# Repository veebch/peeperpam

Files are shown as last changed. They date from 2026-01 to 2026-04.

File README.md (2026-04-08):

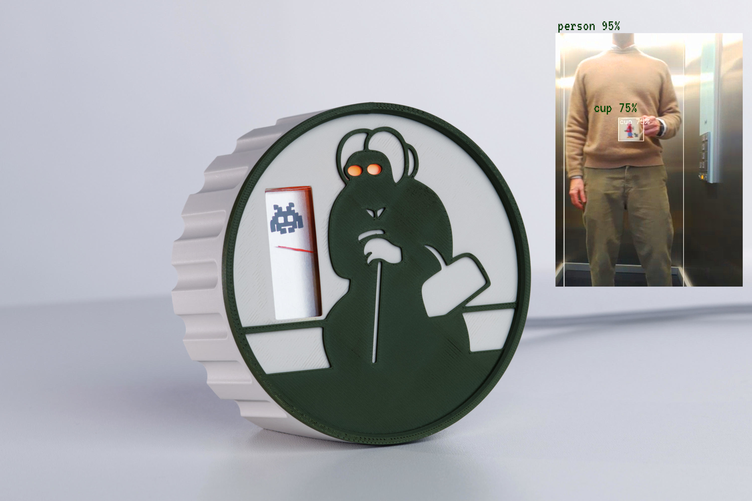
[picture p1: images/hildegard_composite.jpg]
Sketch


 

# Hildegard

A Computer Vision Sentry 

It uses a Raspberry Pi 5 with a camera and Raspberry Pi AI HAT+ 2 as the server, and a Pico W as the client. The system detects all objects but provides priority-based responses: person+cup combinations trigger 100% alerts, person detection alone triggers 70% response, cup detection triggers 30% response, and other interesting objects trigger 10% response. Alerts are sent via WebSocket with RGB LED color changes, PWM-controlled analog needle movement showing detection confidence, and UFO sound alerts for detections above 50% threshold.

## Explainer Video

Here's an overview video of the build and a demo of it in action (it shows the initial red led only version):

YouTube (https://www.youtube.com/watch?v=Vn3WaVIr5v0)

## Project Structure

### Server Components
- **combined_monitor.py** - Complete Raspberry Pi camera monitoring system that captures video, performs object detection using AI kit, and broadcasts all detected objects with confidence scores via WebSocket

### Client Components  
- **main.py** - MicroPython WebSocket client for Pico W that receives detection data and provides priority-based responses:
  - Person + Cup: 100% PWM alert
  - Person only: 70% PWM response 
  - Cup only: 30% PWM response
  - Other objects: 10% PWM response
  - LED color transitions from green (0%) to red (100%) based on detection priority

##  Materials
### Server 
- Raspberry Pi 5
- Raspberry Pi AI+ 2 Kit
- Camera module 

### Detector
- Analogue voltmeter (5V) 
- Pico W
- 220 Ohm resistor
- 1K Ohm resistor
- MOSFET (We used a Small Signal BS170)
- A 4 legged RGB LED
- Passive buzzer

## Assembly

### Server

Connect the M2 expansion board from the AI kit to the Pi 5, connect the 22 pin ribbon cable from the CAM/DISP 0 port on the Pi.

### Detector

- From the Pico, GPIO 27 is soldered to the 1K Ohm resistor which in turn is soldered to the gate (middle pin) of the MOSFET. 
- The VSYS connection on the Pico is connected the positive terminal of the voltmeter. 
- The Cathode (negative) leg of the LED is connected to a GND pin on the Pico in series with the 220 ohm resistor. The Red, Green and Blue legs are connected to GP18, GP19 and GP20 respectively
- The passive buzzer positive terminal is connected to GPIO 15, and the negative terminal to GND
- The Source leg of the MOSFET is connected to the Negative terminal on the voltmeter, the Drain leg of the MOSFET is then connected to a GND GPIO on the Pico W. 

## Installing

First, make sure you have the rpicam-apps files in your home directory
```
cd ~
git clone https://github.com/raspberrypi/rpicam-apps
```

Copy this repository to the Pi 5 using the commands 
```
git clone https://github.com/veebch/peeperpam.git
```
Then copy the file `main.py` to the pico using Ampy (or Thonny)

## Running

### Prerequisites
Make sure you have the rpicam-apps installed:
```bash
cd ~
git clone https://github.com/raspberrypi/rpicam-apps
```

### Start the Complete Monitoring System
Set up Python environment and run the integrated server:
```bash
python3 -m venv ~/.venv
source ~/.venv/bin/activate
cd ~/peeperpam
pip install websockets  # Install required WebSocket library
python3 combined_monitor.py
```

This single command starts both the camera monitoring and WebSocket server that broadcasts all detected objects.

### Configure and Deploy the Client
1. **Edit configuration in `config.py`**:
   - WiFi credentials: Replace `SSID` and `PASSWORD` with your network details
   - Object detection: Customize `INTERESTING_OBJECTS` list to monitor different objects (from the [COCO 80](https://blog.roboflow.com/microsoft-coco-classes/) list by default but you can train on other image data)
   - Detection priorities: Adjust `PERSON_SCALE`, `CUP_SCALE`, and `OTHER_SCALE` values
   - Sound settings: Modify `SOUND_THRESHOLD`, `SOUND_COOLDOWN`, and UFO sound parameters
   - Hardware pins: Change pin assignments if using different GPIO connections

2. Copy both `main.py` and `config.py` to your Pico W using Ampy, Thonny, or your preferred method

3. Power on the Pico W - it will automatically connect to WiFi and start receiving detection alerts

### System Operation
- The system detects all objects but responds with different priority levels
- RGB LED changes from green (low priority) to red (high priority) 
- Analog needle shows detection confidence scaled by priority level
- UFO sound alert plays when detection confidence exceeds 50% threshold
- Sound includes 5-second cooldown to prevent constant triggering
- WebSocket connection automatically reconnects if interrupted

## Caveats

The MOSFET may be overkill for the LED and Voltmeter, but if you plan to use something that draws more current than an LED, then using SYSBUS means the 'alarm' peripheral can draw a lot more current than just a GPIO pin set to high (~16mA).

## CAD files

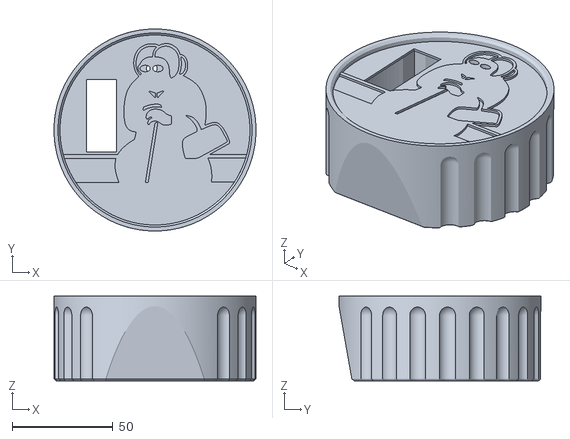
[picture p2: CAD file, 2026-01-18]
3d/Hildegard-enclosure.stl
100.0 x 100.0 x 42.0

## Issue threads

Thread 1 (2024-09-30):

Pico W Detector Details

holmesha, 2024-09-30:
Hello! I was wondering if you could provide a bit more detail on the detector connections. Maybe a diagram or a picture where I can see the wires? I'm not great at the electrical engineering part, but I love the idea of the detector. I'm going to attempt to train the model to recognize raccoons because I have a family of racoons making my cat's life a nightmare lol, but I never catch them in the act!

veebch, 2024-09-30:
Hey there,  Racooncam sounds like a winner. I'll add a photo to the readme this  morning. Hopefully the janky soldering will not cause too many screams on the internet. I'll leave this open until I actually add the photo.

veebch, 2024-09-30:
Done! I want a racoon update once it's all done :)

Closed 2024-09-30.

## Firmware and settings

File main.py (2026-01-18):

import network
import usocket as socket
import ubinascii
import uasyncio as asyncio
import os
import time
import re
import ujson as json
import math
from machine import Pin, PWM
from config import *

# Hardware pin definitions
RED_PIN = 18
GREEN_PIN = 19
BLUE_PIN = 20
ALERT_PIN = 27
BUZZER_PIN = 15

# Startup sequence timing
STARTUP_RAMP_DURATION = 2.0  # Seconds for ramp up/down
STARTUP_STEPS = 100          # Number of steps in ramp sequence

# RGB LED pins with PWM
red_pin = PWM(Pin(RED_PIN))
green_pin = PWM(Pin(GREEN_PIN))
blue_pin = PWM(Pin(BLUE_PIN))

# Set PWM frequency for LED
for pin in [red_pin, green_pin, blue_pin]:
    pin.freq(1000)
    pin.duty_u16(0)

# Alert PWM pin
alert = PWM(Pin(ALERT_PIN))
alert.freq(1000)

# Buzzer pin for sound alerts
buzzer = PWM(Pin(BUZZER_PIN))
buzzer.duty_u16(0)  # start silent

# Sound threshold and state tracking
sound_playing = False
last_sound_time = 0

# Connect to Wi-Fi
print("Connecting to WiFi network:", SSID)
wlan = network.WLAN(network.STA_IF)
wlan.active(True)
print("WiFi interface activated")

# Force fresh connection - disconnect first if connected
if wlan.isconnected():
    print("Forcing WiFi disconnect to ensure fresh connection...")
    wlan.disconnect()
    time.sleep(2)  # Wait for disconnect
    print("WiFi disconnected")

print("Attempting to connect...")
wlan.connect(SSID, PASSWORD)
print("Connection request sent, waiting for connection...")

connection_attempts = 0
while not wlan.isconnected() and connection_attempts < WIFI_MAX_ATTEMPTS:
    connection_attempts += 1
    if connection_attempts % 10 == 0:  # Log every 1 second
        print("Still connecting... (attempt", connection_attempts, ")")
    time.sleep(WIFI_RETRY_DELAY)

if not wlan.isconnected():
    print("Failed to connect to WiFi after", WIFI_MAX_ATTEMPTS/10, "seconds")
    print("WiFi Status:", wlan.status())
    print("Check your SSID and password")
    # Don't continue without WiFi
    while True:
        time.sleep(1)

print("Connected to Wi-Fi successfully")
ip_info = wlan.ifconfig()
print("IP Address:", ip_info[0])
print("Subnet Mask:", ip_info[1])
print("Gateway:", ip_info[2])
print("DNS:", ip_info[3])

# Wait a moment for network stack to fully initialize
print("Waiting for network stack to stabilize...")
time.sleep(NETWORK_STABILIZE_DELAY)

def set_rgb_pwm(r, g, b):
    """Set RGB LED color using PWM values (0-65535)"""
    red_pin.duty_u16(r)
    green_pin.duty_u16(g)
    blue_pin.duty_u16(b)

def update_led_from_pwm(duty_ratio):
    """Update LED color based on PWM duty cycle (0.0 to 1.0)
    Green at 0%, transitions to red at 100%"""
    red = int(duty_ratio * 65535)
    green = int((1 - duty_ratio) * 65535)
    set_rgb_pwm(red, green, 0)

def set_duty_cycle(duty, verbose=True):
    # Clamp duty to 0.0-1.0 range
    original_duty = duty
    duty = max(0.0, min(1.0, duty))
    if original_duty != duty and verbose:
        print("WARNING: Duty cycle clamped from", original_duty, "to", duty)
    
    pwm_value = int(duty * 65535)
    alert.duty_u16(pwm_value)
    if verbose:
        print("PWM set to", duty, "(", pwm_value, "/65535)")
    
    # Update LED color to match PWM value
    update_led_from_pwm(duty)
    if verbose:
        red_val = int(duty*65535)
        green_val = int((1-duty)*65535)
        print("LED color updated (red:", red_val, ", green:", green_val, ")")

async def play_ufo_sound():
    """Play UFO sound effect asynchronously"""
    global sound_playing
    sound_playing = True
    print("Playing UFO sound alert!")
    
    start_time = time.ticks_us()
    total_time = UFO_FADE_IN_SEC + UFO_SUSTAIN_SEC + UFO_FADE_OUT_SEC
    
    try:
        while True:
            # Elapsed time in seconds
            t = time.ticks_diff(time.ticks_us(), start_time) / 1_000_000
            if t > total_time:
                break  # stop after full sound duration

            # Fade-in / sustain / fade-out scaling
            if t < UFO_FADE_IN_SEC:
                scale = t / UFO_FADE_IN_SEC
            elif t < UFO_FADE_IN_SEC + UFO_SUSTAIN_SEC:
                scale = 1.0
            else:
                scale = (total_time - t) / UFO_FADE_OUT_SEC

            # Pitch modulation (LFO)
            pitch_mod = math.sin(2 * math.pi * UFO_LFO_RATE * t)
            freq = int(UFO_BASE_FREQ + UFO_FREQ_DEPTH * pitch_mod)
            buzzer.freq(freq)

            # Volume modulation with global volume
            phase_vol = 2 * math.pi * UFO_LFO_RATE * t + math.pi / 4
            vol_mod = (math.sin(phase_vol) * UFO_VOLUME_DEPTH + 1 - UFO_VOLUME_DEPTH) / 2
            vol_mod *= UFO_VOLUME

            # Duty cycle with fade
            buzzer.duty_u16(int(vol_mod * scale * 65535))

            await asyncio.sleep_ms(UFO_STEP_MS)

    except Exception as e:
        print("Sound error:", e)
    finally:
        buzzer.duty_u16(0)  # ensure buzzer is silent
        sound_playing = False
        print("UFO sound complete")

async def startup_sequence():
    """Startup sequence: ramp up to full over 2 seconds, then down over 2 seconds"""
    global last_sound_time, sound_playing
    
    step_duration = STARTUP_RAMP_DURATION / STARTUP_STEPS
    sound_triggered = False  # Track if we've triggered sound during startup

    # Ramp up (reduce logging)
    print("Starting up - ramping up...")
    for i in range(STARTUP_STEPS + 1):
        duty = i / STARTUP_STEPS
        set_duty_cycle(duty, verbose=False)  # Suppress verbose output during startup
        
        # Check if we should trigger sound during startup ramp
        if (duty > SOUND_THRESHOLD and 
            not sound_triggered and 
            not sound_playing):
            
            print(f"Startup PWM reached threshold ({duty:.2f} > {SOUND_THRESHOLD}) - triggering startup sound!")
            sound_triggered = True
            last_sound_time = time.time()  # Update last sound time
            # Start sound in background
            asyncio.create_task(play_ufo_sound())
        
        await asyncio.sleep(step_duration)

    # Ramp down
    print("Ramping down...")
    for i in range(STARTUP_STEPS, -1, -1):
        duty = i / STARTUP_STEPS
        set_duty_cycle(duty, verbose=False)  # Suppress verbose output during startup
        await asyncio.sleep(step_duration)

    print("Startup complete")

class WebSocketClient:
    def __init__(self, server_ip, port):
        self.server_ip = server_ip
        self.port = port
        self.sock = None

    def connect(self):
        while True:
            try:
                print("Resolving server address...")
                addr_info = socket.getaddrinfo(self.server_ip, self.port, socket.AF_INET)  # Force IPv4
                addr = addr_info[0][-1]
                print("Server address resolved to:", addr)
                
                print("Creating socket...")
                self.sock = socket.socket()
                print("Connecting to server...")
                self.sock.connect(addr)
                print("Connected to", self.server_ip, ":", self.port)

                # Handshake - use original working format
                sec_websocket_key = ubinascii.b2a_base64(os.urandom(16)).strip()
                handshake = (b"GET / HTTP/1.1\r\n"
                             b"Host: %s:%d\r\n"
                             b"Upgrade: websocket\r\n"
                             b"Connection: Upgrade\r\n"
                             b"Sec-WebSocket-Key: %s\r\n"
                             b"Sec-WebSocket-Version: 13\r\n\r\n") % (self.server_ip.encode(), self.port, sec_websocket_key)
                self.sock.send(handshake)
                response = self.sock.recv(1024)
                print("Handshake response:", response)
                if b"101" not in response:
                    raise ValueError("Handshake failed")
                print("Handshake successful")
                break
            except (OSError, ValueError) as e:
                print("Connection error:", e)
                print("Error type:", type(e).__name__)
                if hasattr(e, 'errno'):
                    print("Error number:", e.errno)
                if self.sock:
                    self.sock.close()
                self.sock = None
                print("Retrying connection in 5 seconds...")
                time.sleep(WEBSOCKET_RETRY_DELAY)

    def read_bytes(self, num_bytes):
        data = bytearray()
        while len(data) < num_bytes:
            packet = self.sock.recv(num_bytes - len(data))
            if not packet:
                raise ValueError("Connection closed before receiving all data")
            data.extend(packet)
        return data

    def recv(self):
        try:
            first_byte, second_byte = self.read_bytes(2)
            fin = first_byte & 0b10000000
            opcode = first_byte & 0b00001111
            masked = second_byte & 0b10000000
            payload_length = second_byte & 0b01111111

            if payload_length == 126:
                payload_length = int.from_bytes(self.read_bytes(2), 'big')
            elif payload_length == 127:
                payload_length = int.from_bytes(self.read_bytes(8), 'big')

            if masked:
                masking_key = self.read_bytes(4)
                payload = bytearray(self.read_bytes(payload_length))
                for i in range(payload_length):
                    payload[i] ^= masking_key[i % 4]
            else:
                payload = self.read_bytes(payload_length)

            if opcode == 0x8:  # Close frame
                print("Received close frame")
                self.send_close_frame()
                return None

            if opcode == 0x9:  # Ping frame
                print("Received ping frame")
                self.send_pong_frame()
                return None

            message = payload.decode('utf-8')
            print("Received message:", message)
            return message
        except OSError as e:
            print("Recv error:", e)
            self.close()
            return None

    def send_frame(self, opcode, payload=b''):
        frame = bytearray()
        frame.append(0x80 | opcode)
        payload_length = len(payload)
        if payload_length < 126:
            frame.append(0x80 | payload_length)
        elif payload_length <= 0xFFFF:
            frame.append(0x80 | 126)
            frame.extend(payload_length.to_bytes(2, 'big'))
        else:
            frame.append(0x80 | 127)
            frame.extend(payload_length.to_bytes(8, 'big'))
        masking_key = os.urandom(4)
        frame.extend(masking_key)
        if payload:
            masked_payload = bytearray(payload)
            for i in range(len(masked_payload)):
                masked_payload[i] ^= masking_key[i % 4]
            frame.extend(masked_payload)
        self.sock.send(frame)

    def send_close_frame(self):
        self.send_frame(0x8)
        print("Close frame sent")

    def send_pong_frame(self):
        self.send_frame(0xA)
        print("Pong frame sent")

    def close(self):
        if self.sock:
            try:
                self.send_close_frame()
            except Exception as e:
                print("Error during close frame:", e)
            self.sock.close()
            self.sock = None
        print("Socket closed")

def parse_detection_data(message):
    """Parse detection data and return appropriate PWM duty cycle"""
    print("Parsing detection data...")
    try:
        data = json.loads(message)
        print("Successfully parsed JSON data")
        
        all_objects = data.get("all_objects", {})
        avg_confidence = data.get("average_confidence", 0.0)
        is_alert = data.get("alert", False)
        
        if all_objects:
            print("All objects detected:", all_objects)
            
            # Priority 1: High alert for person+cup combination
            if is_alert:
                print("HIGH PRIORITY ALERT!")
                conf_percent = avg_confidence * 100
                print("Alert confidence:", avg_confidence, "(", conf_percent, "%)")
                return avg_confidence
            
            # Priority 2: Respond to person detection (medium priority)
            elif "person" in all_objects:
                person_data = all_objects["person"]
                if isinstance(person_data, dict):
                    person_conf = person_data["confidence"]
                    print("Person detected - confidence:", person_conf)
                    # Scale down for person-only detection
                    return person_conf * PERSON_SCALE
                    
            # Priority 3: Respond to cup detection (lower priority)
            elif "cup" in all_objects:
                cup_data = all_objects["cup"]
                if isinstance(cup_data, dict):
                    cup_conf = cup_data["confidence"]
                    print("Cup detected - confidence:", cup_conf)
                    # Scale down for cup-only detection
                    return cup_conf * CUP_SCALE
                    
            # Priority 4: Other interesting objects (very low response)
            else:
                for obj in INTERESTING_OBJECTS:
                    if obj in all_objects:
                        obj_data = all_objects[obj]
                        if isinstance(obj_data, dict):
                            obj_conf = obj_data["confidence"]
                            print(obj + " detected - confidence:", obj_conf)
                            # Very low response for other objects
                            return obj_conf * OTHER_SCALE
                            
                print("Objects detected but no priority matches")
                
        return 0.0  # No significant objects detected
            
    except (ValueError, KeyError) as e:
        
        # Fallback to old string parsing for compatibility
        return parse_string_legacy(message)
    
    return 0.0

def parse_string_legacy(input_string):
    """Legacy string parsing for backward compatibility"""
    # Check if the string contains the word 'person'
    if 'person' in input_string:
        # Use regex to find the number in parentheses
        match = re.search(r'\(([\d.]+)\)', input_string)
        if match:
            number_in_parentheses = float(match.group(1))
        else:
            number_in_parentheses = 0
    else:
        number_in_parentheses = 0

    return number_in_parentheses

async def perform_action(signal):
    global last_sound_time, sound_playing
    print("Processing detection signal!")
    # Parse the detection data (JSON or legacy string)
    duty = parse_detection_data(signal)
    if duty > 0:
        print("Setting PWM duty to:", duty)
        set_duty_cycle(duty)
        
        # Check if we should trigger sound alert
        current_time = time.time()
        if (duty > SOUND_THRESHOLD and 
            not sound_playing and 
            (current_time - last_sound_time) > SOUND_COOLDOWN):
            
            print(f"Detection above threshold ({duty:.2f} > {SOUND_THRESHOLD}) - triggering sound!")
            last_sound_time = current_time
            # Start sound in background
            asyncio.create_task(play_ufo_sound())
        
    else:
        print("No significant detection - PWM remains at current level")

async def listen_for_signal():
    while True:
        ws = WebSocketClient(SERVER_IP, SERVER_PORT)
        try:
            ws.connect()
            while True:
                signal = ws.recv()
                if signal:
                    # Handle all JSON detection messages
                    if signal.startswith('{'):
                        print("Detection message received")
                        await perform_action(signal)
                    elif "Object" in signal or "person" in signal:
                        print("Legacy signal received:", signal)
                        await perform_action(signal)
                    else:
                        print("Server message:", signal)
        except Exception as e:
            print("Error:", e)
        finally:
            ws.close()
            await asyncio.sleep(WEBSOCKET_RETRY_DELAY)

async def main():
    """Main async function to run startup and then listen for signals"""
    # Run startup sequence
    await startup_sequence()
    # Start listening for detection signals
    await listen_for_signal()

# Run the main async function
asyncio.run(main())

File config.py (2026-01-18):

# PeeperPam Configuration File
# Edit these values to customize detection behavior and network settings

# ====== NETWORK SETTINGS ======
# WiFi credentials
SSID = "whyayefi"  # Replace with your actual WiFi SSID  
PASSWORD = "your_actual_password"  # Replace with your actual WiFi password

# Server connection
SERVER_IP = "peeper.local"  # Use hostname or IP address of your Raspberry Pi
SERVER_PORT = 6789

# ====== DETECTION PRIORITIES ======
# Object priority scaling factors (0.0 = no response, 1.0 = full response)
PERSON_SCALE = 0.7      # Person detection alone gets 70% response
CUP_SCALE = 0.3         # Cup detection alone gets 30% response  
OTHER_SCALE = 0.1       # Other interesting objects get 10% response

# High priority objects (will trigger person/cup scaled response)
PRIMARY_OBJECTS = ["person", "cup"]

# Interesting objects that trigger low-level responses
INTERESTING_OBJECTS = [
    "bottle", 
    "laptop", 
    "cell phone", 
    "book", 
    "tv",
    "mouse",
    "keyboard",
    "remote",
    "wine glass",
    "banana",
    "apple",
    "sandwich"
]

# ====== SOUND SETTINGS ======
# Sound trigger threshold (0.0 to 1.0)
SOUND_THRESHOLD = 0.5   # Trigger sound when detection confidence > 50%

# Sound timing
SOUND_COOLDOWN = 5.0    # Minimum seconds between sound triggers

# UFO sound parameters
UFO_BASE_FREQ = 600         # Base frequency (Hz)
UFO_FREQ_DEPTH = 300        # Pitch modulation depth
UFO_LFO_RATE = 15 / 2.3     # Pitch LFO frequency (Hz)
UFO_VOLUME_DEPTH = 0.3      # Amplitude modulation depth (0.0 - 1)
UFO_VOLUME = 1.0            # Global volume scale (0.0 - 1.0)

# Sound timing phases
UFO_FADE_IN_SEC = 0.1
UFO_SUSTAIN_SEC = 2.0
UFO_FADE_OUT_SEC = 1.0
UFO_STEP_MS = 5             # CPU delay between updates

# ====== CONNECTION SETTINGS ======
# WiFi connection parameters
WIFI_MAX_ATTEMPTS = 100     # Maximum connection attempts (10 seconds total)
WIFI_RETRY_DELAY = 0.1      # Seconds between connection attempts

# Network stabilization
NETWORK_STABILIZE_DELAY = 3  # Seconds to wait after WiFi connection

# WebSocket reconnection
WEBSOCKET_RETRY_DELAY = 5   # Seconds to wait before reconnecting on error

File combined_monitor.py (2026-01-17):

#!/usr/bin/env python3
import asyncio
import websockets
import subprocess
import re
import signal
import sys
import json
import time
import logging
import argparse
from collections import defaultdict
from datetime import datetime

class CameraMonitor:
    def __init__(self, show_preview=False):
        self.current_detection = {"person": 0, "cup": 0}
        self.current_confidence = {"person": 0.0, "cup": 0.0}
        self.all_objects = {}
        self.signal_active = False
        self.connected_clients = set()
        self.camera_process = None
        self.frame_count = 0
        self.last_detection_time = None
        self.show_preview = show_preview

        # Setup logging
        logging.basicConfig(
            level=logging.INFO,
            format='%(asctime)s - %(levelname)s - %(message)s',
            datefmt='%Y-%m-%d %H:%M:%S'
        )
        self.logger = logging.getLogger(__name__)

    async def start_camera_monitoring(self):
        """Start the camera process and monitor its output"""
        # Use different commands for preview vs headless mode
        if self.show_preview:
            # Use rpicam-hello for preview mode - it's designed for this
            cmd = [
                "rpicam-hello", "-v", "2", "-t", "0",
                "--post-process-file", "/home/pi/rpicam-apps/assets/hailo_yolov8_inference.json",
                "--lores-width", "640", "--lores-height", "640"
            ]
        else:
            # Use rpicam-vid for headless mode with output capture
            cmd = [
                "rpicam-vid", "-n", "-v", "2", "-t", "0", "--inline",
                "--post-process-file", "/home/pi/rpicam-apps/assets/hailo_yolov8_inference.json",
                "--width", "640", "--height", "640",
                "--framerate", "10", "-o", "-"
            ]

        mode = "with preview window (rpicam-hello)" if self.show_preview else "headless (rpicam-vid)"
        self.logger.info(f"Starting camera monitoring {mode}...")
        self.logger.info(f"Command: {' '.join(cmd)}")

        if self.show_preview:
            self.logger.info("📺 Preview window should appear for testing")
        else:
            self.logger.info("🔒 Running headless - suitable for SSH connections")

        try:
            self.camera_process = await asyncio.create_subprocess_exec(
                *cmd,
                stdout=subprocess.PIPE,
                stderr=subprocess.STDOUT
            )

            self.logger.info("Camera process started successfully")
            await self.process_camera_output()

        except Exception as e:
            self.logger.error(f"Error starting camera: {e}")

    async def process_camera_output(self):
        """Process camera output and detect objects"""
        if not self.camera_process:
            return

        self.logger.info("Starting camera output processing...")

        async for line_bytes in self.camera_process.stdout:
            try:
                line = line_bytes.decode('utf-8').strip()

                # Log all output for debugging (you can reduce this later)
                if line and not line.startswith('#'):
                    self.logger.debug(f"Camera output: {line}")

                # Parse YOLO detection output
                if self.is_detection_line(line):
                    self.frame_count += 1
                    self.last_detection_time = datetime.now()

                    self.logger.info(f"Frame {self.frame_count}: Processing detection line")
                    self.parse_detection_line(line)
                    await self.update_signal_status()

            except UnicodeDecodeError as e:
                self.logger.warning(f"Failed to decode line: {e}")
            except Exception as e:
                self.logger.error(f"Error processing camera output: {e}")

    def is_detection_line(self, line):
        """Check if this line contains object detection info"""
        detection_indicators = [
            "Object detected:",
            "Detection:",
            "Found:",
            "person",
            "cup",
            "bottle",
            "chair",
            "dining table"
        ]
        return any(indicator in line.lower() for indicator in detection_indicators)

    def parse_detection_line(self, line):
        """Parse a detection line and update object counts with confidence"""
        # Reset for this frame
        self.current_detection = {"person": 0, "cup": 0}
        self.current_confidence = {"person": 0.0, "cup": 0.0}
        self.all_objects = {}

        line_lower = line.lower()

        # Log the raw detection line
        self.logger.info(f"Raw detection: {line}")

        # Parse different object types and their counts with confidence
        objects_found = []
        
        # Define all objects we want to detect with confidence
        target_objects = ["person", "cup", "bottle", "chair", "dining table", "laptop", "cell phone", "book", "mouse", "keyboard", "tv", "car", "bicycle", "dog", "cat"]
        
        for obj in target_objects:
            # Pattern to match: object_name[optional_stuff] (confidence_score)
            pattern = fr'{obj}[^(]*\(([\d.]+)\)'
            matches = re.findall(pattern, line_lower)
            if matches:
                confidences = [float(conf) for conf in matches]
                avg_conf = sum(confidences) / len(confidences)
                self.all_objects[obj] = {"count": len(matches), "confidence": avg_conf}
                objects_found.append(f"{len(matches)} {obj}(s) @{avg_conf:.2f}")
                
                # Update legacy fields for backwards compatibility
                if obj == "person":
                    self.current_detection["person"] = len(matches)
                    self.current_confidence["person"] = avg_conf
                elif obj == "cup":
                    self.current_detection["cup"] = len(matches)
                    self.current_confidence["cup"] = avg_conf

        # Verbose logging
        if objects_found:
            self.logger.info(f"Frame {self.frame_count} objects: {', '.join(objects_found)}")
        else:
            self.logger.debug(f"Frame {self.frame_count}: No objects detected")

    async def update_signal_status(self):
        """Broadcast detection status for any detected objects"""
        # Always broadcast if we have any objects detected
        has_objects = bool(self.all_objects)
        
        # Special case: high priority alert for person+cup combination
        person_cup_alert = (
            self.current_detection["person"] == 1 and
            self.current_detection["cup"] == 1
        )
        
        if has_objects:
            await self.broadcast_signal(alert=person_cup_alert)
            if person_cup_alert:
                self.logger.warning("🚨 HIGH PRIORITY: 1 person + 1 cup detected!")

        # Update signal status for legacy compatibility
        self.signal_active = person_cup_alert
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

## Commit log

2026-01-13 Hildegard and colour LED
2026-01-14 Revise LED and GPIO details in README
    Updated LED description and GPIO connections in the assembly instructions.
2026-01-14 Revise power-up and LED indication instructions
    Updated device power-up behavior description and LED indication.
2026-01-14 Replace Wi-Fi credentials with placeholders
    Updated Wi-Fi credentials placeholders for clarity.
    [main.py]
2026-01-17 Add combined camera monitor with 1 person + 1 cup detection
    - Combines camera_monitor.sh and server.py functionality
    - Eliminates file I/O overhead by processing camera output directly
    - Triggers WebSocket alerts only when exactly 1 person AND 1 cup detected
    - Improved performance with real-time processing and proper async handling
    - Single process replaces two separate programs
    [combined_monitor.py]
2026-01-17 Complete IoT object detection system
    - Enhanced combined_monitor.py to broadcast all detected objects with confidence scores
    - Updated main.py with priority-based PWM control for different object types
    - Removed test files and debug scripts for clean production codebase
    - WebSocket communication working with chair detection confirmed
    - Priority system: person+cup (100%), person (70%), cup (30%), other objects (10%)
2026-01-17 Remove emojis from code and documentation
    - Clean up main.py print statements by removing all emoji characters
    - Update README.md documentation to reflect current project structure
    - Maintain professional, emoji-free codebase
2026-01-17 Fix f-string formatting issue in object detection
    - Replace f-string with string concatenation to avoid encoding issues
    - Resolves 'str' object has no attribute 'title' error when detecting bottles and other objects
    [main.py]
2026-01-17 Fix object name formatting issue
    - Replace .title() with .capitalize() and explicit str() conversion
    - Resolves string attribute error when detecting bottles and other objects
    - Ensures robust string handling for all object types
    [main.py]
2026-01-17 Fix MicroPython compatibility: remove capitalize() method call
    - Remove str().capitalize() which is not available in MicroPython
    - This fixes the crash when detecting objects like bottles
    - Object names are now printed as-is without capitalization
    [main.py]
2026-01-18 Integrate UFO sound functionality into main.py
    - Add threshold-based sound alerts with 50% trigger threshold
    - Implement async UFO sound generation with fade-in/sustain/fade-out
    - Add 5-second cooldown to prevent constant sound triggers
    - Remove redundant sound.py file - all functionality now in main.py
    - Sound triggers on person detection, high alerts, or significant objects
    [main.py]
2026-01-18 Add startup sound trigger and update README with buzzer info
    - Startup sequence now triggers UFO sound when PWM reaches 50% threshold
    - Added async startup_sequence() with sound integration
    - Updated main() function to properly handle async startup
    - Added passive buzzer (GPIO 15) to materials list and assembly instructions
    - Updated project description to mention UFO sound alerts
    - Added sound functionality details to system operation section
    [main.py]
2026-01-18 Correct Raspberry Pi AI kit reference in README
    Updated the README to reflect the use of Raspberry Pi AIHAT 2 instead of Raspberry Pi AI kit.
2026-01-18 platform for pico
    [Hildegard-enclosure.stl]
2026-01-19 Update Raspberry Pi AI Kit to Raspberry Pi AI+ 2 Kit
2026-01-21 Fix duplicate MOSFET connection description in README
    Removed duplicate line about MOSFET connections.
